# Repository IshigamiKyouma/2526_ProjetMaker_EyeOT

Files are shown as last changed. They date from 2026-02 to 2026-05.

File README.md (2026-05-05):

# 2526_ProjetMaker_EyeOT

Projet de MANSARD Johann réalisé dans le cadre de l'option Maker.\
Lien de la vidéo: https://youtube.com/shorts/I4skJVQ_Xr0?feature=share
Lien du répo avec les exos: https://github.com/IshigamiKyouma/2526_Maker_Exercises

## 1. Description du Projet et rétroplanning
### 1.1. Contexte et objectifs

En tant que joueur passionné de League of Legends et "Main Vel'Koz", j'ai toujours été fasciné par le concept de ce champion :
une entité du Néant qui déconstruit la réalité pour accumuler des connaissances.

<details>
  <summary>Cliquez ici pour voir le modèle 3D de Vel'Koz</summary>
  <br>
  <div align="center">
    Modèle 3D Vel'Koz
    <p><i>Rendu 3D du modèle Vel'Koz (Source : Riot Games)</i></p>
  </div>
</details>

L'idée de ce projet est née d'une envie simple: briser le quatrième mur. Je ne voulais plus que Vel'Koz soit uniquement une image sur mon écran, mais qu'il devienne un compagnon physique capable de réagir, en temps réel, à l'intensité de mes parties.

L'objectif est de créer une figurine interactive qui agit comme une extension sensorielle du jeu. Grâce à l'intégration de l'API de Riot Games et de composants électroniques, la figurine "vit" au rythme de la faille:

* Réaction aux événements: Un feedback visuel lors de l'application des stacks de passif (LEDs hautes qui s'allument une à une) puis la centrale lors de l'activation du passif "Organic Deconstruction".

* Analyse des mouvements: Les tentacules se déplacent en fonction de la vitesse de déplacement en jeu

### 1.2. Solutions techniques

* **Cœur du système :** Microcontrôleur **STM32**, choisi pour sa gestion fluide des interruptions et ses multiples canaux PWM nécessaires au pilotage synchrone des servomoteurs et du bus NeoPixel.
* **Communication de données :** Script en **Python** interrogeant la *Live Client Data API* de Riot Games à haute fréquence (HTTPS) et transmettant les états à la STM via une liaison **Série (USB)**.
* **Actionneurs & Visuels :**  3 Servomoteurs pour l'animation cinétique.
    * 3 LEDs adressables (NeoPixel) pour les stacks et 1 bloc circulaire pour l'œil central.
* **Gestion de l'énergie :** Conception d'un **PCB dédié** à la distribution de puissance, incluant un filtrage par condensateurs pour lisser les appels de courant des servos et une alimentation externe **5V 3A**.
* **Structure & Design :** Modélisation CAO et impression 3D. Le châssis est conçu pour masquer l'électronique dans le socle.

---

### 1.3. Obtention des valeurs

Pour obtenir:
* la vitesse de déplacement du joueur: on utilisera directement l'API
* les stacks de passif: Apparaissent visuelement quand on clique sur un ennemie

### Mécanisme de mouvement : Le système à câbles
Pour reproduire le mouvement fluide et "invertébré" des tentacules de Vel'Koz avec seulement 3 servomoteurs, le projet utilise un système de **flexion par câbles (tendeurs)** :

* **Principe :** Chaque tentacule est imprimée en matériau semi-rigide ou composée de vertèbres articulées.
* **Transmission :** Un câble (type fil de pêche ou nylon) parcourt l'intérieur de la tentacule jusqu'à l'extrémité. 
* **Actionnement :** Le servomoteur, situé dans la base, tire sur le câble pour courber la structure. Un ressort interne ou la mémoire de forme du plastique permet le retour à la position initiale.
* **Résultat :** Cela permet d'obtenir une ondulation organique plutôt qu'une rotation robotique rigide.

---

### Rétro-planning

| Session | Phase | Objectif principal |
| --- | ----- | --- |
| **TP 1** | **PoC Logiciel** | Script Python : récupération des données API et envoi vers l'ESP32. |
| **TP 2** | **Électronique** | Montage breadboard : test simultané des 3 servos et des LEDs. |
| **TP 3** | **Design PCB** | Routage du circuit d'alimentation et préparation à la soudure. |
| **TP 4** | **Modélisation 3D** | CAO du corps et du mécanisme de tension des tentacules. |
| **TP 5** | **Mécanique** | Assemblage des servos et tests des câbles de traction. |
| **TP 6** | **Intégration** | Soudure finale sur PCB et insertion dans la structure 3D. |
| **TP 7** | **Calibration** | Mapping des data LoL -> angles de servos et finitions visuelles. |

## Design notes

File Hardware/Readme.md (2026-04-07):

On rentrera ici plus en détail dans les problèmes et solutions techniques trouvées.

### Mouvement des tentacules 

La solution usuelle pour simuler des tentacules utilise 4 servos par tentacule. Afin de rendre le système plus compact et simple à commander, on utilisera 1 seul moteur.

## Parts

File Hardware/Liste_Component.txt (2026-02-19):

3 Stepper motor : 11HS18-0674S / 14HM11-0404S 
3 motor driver: TM2225-SA-T
Neopixels : 
STM32: STM32G474RET6
Bloc secteur 5V 4A
3 level-shifter 3.3V -> 5V pour chaque moteur
1 level-shifter 3.3V -> 5V pour les neopixels
1 Step-Down Alim-> STM : Wurth	171013801

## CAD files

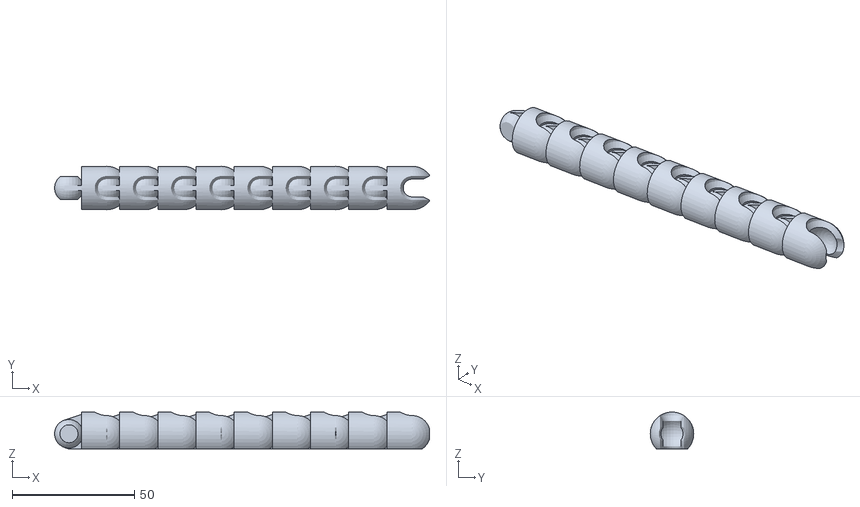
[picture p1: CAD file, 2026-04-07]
CAD/Articulated Vel Koz/articulated_velkoz_side_tentacle_x2.stl
153.2 x 17.8 x 15.1

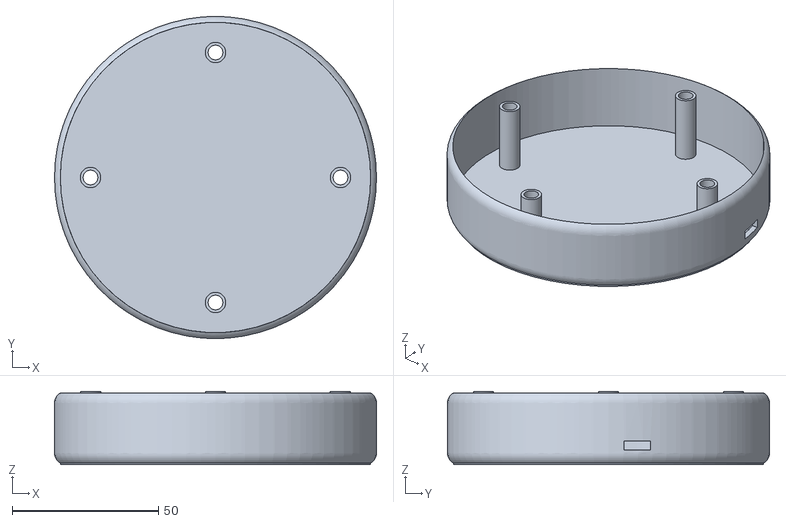
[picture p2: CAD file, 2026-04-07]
CAD/base_velkoz.stl
110.0 x 110.0 x 25.0

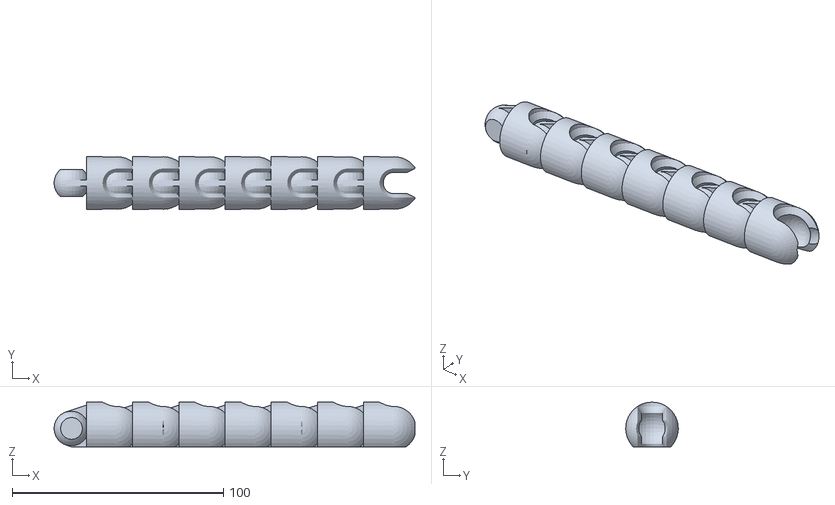
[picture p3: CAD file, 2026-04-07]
CAD/Articulated Vel Koz/articulated_velkoz_rear_tentacle.stl
170.8 x 24.9 x 21.1

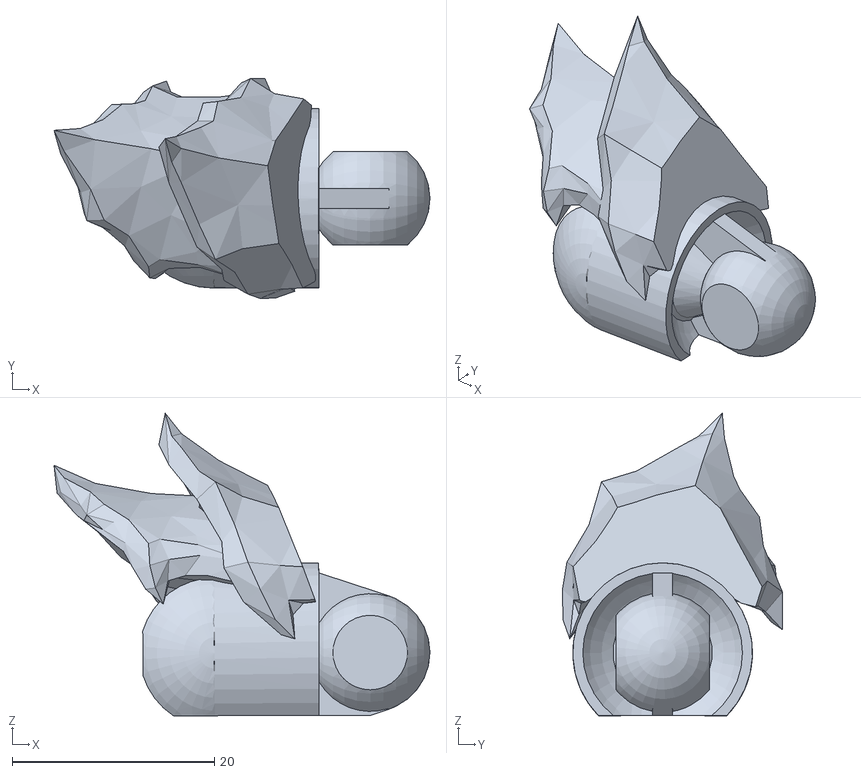
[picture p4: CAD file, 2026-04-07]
CAD/Articulated Vel Koz/articulated_velkoz_right_shoulder.stl
37.2 x 21.8 x 30.0

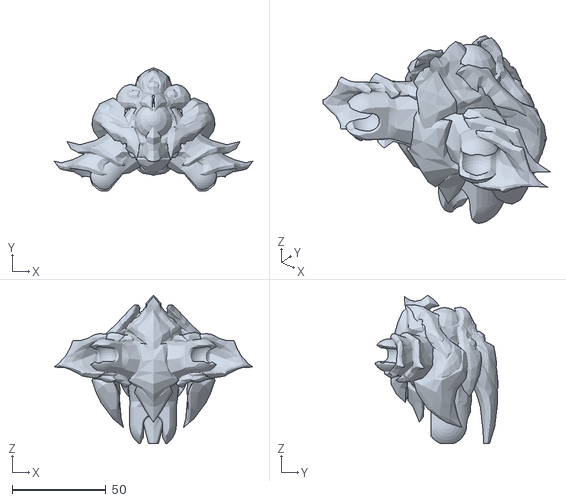
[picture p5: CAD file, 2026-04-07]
CAD/Articulated Vel Koz/articulated_velkoz_body.stl
106.0 x 65.8 x 79.0

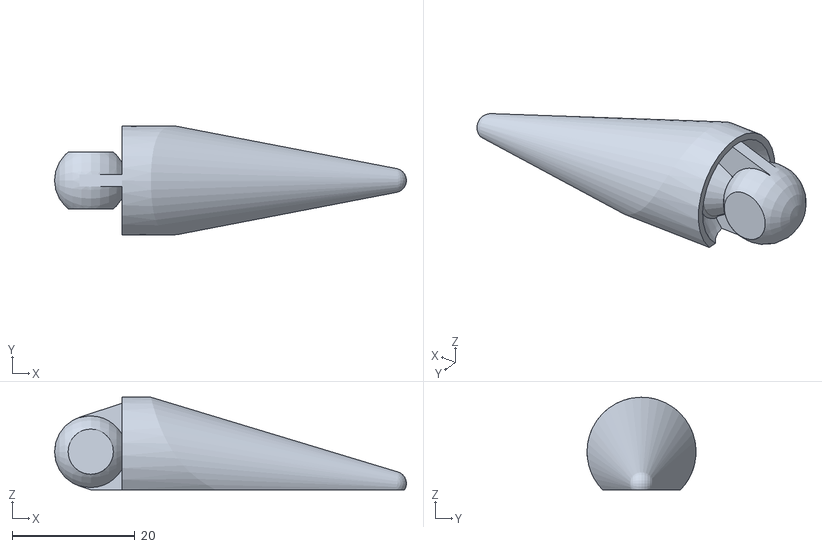
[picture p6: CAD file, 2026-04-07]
CAD/Articulated Vel Koz/articulated_velkoz_side_tip_x2.stl
57.4 x 17.8 x 15.1

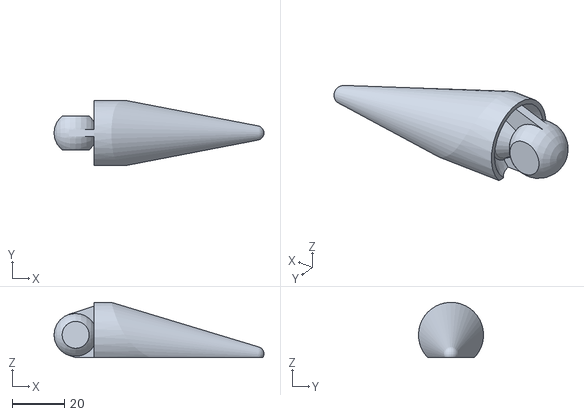
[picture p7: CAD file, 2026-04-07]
CAD/Articulated Vel Koz/articulated_velkoz_rear_tip.stl
80.4 x 24.9 x 21.1

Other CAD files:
CAD/velkoz_base.3mf
CAD/Articulated Vel Koz/articulated_velkoz_left_shoulder.stl
CAD/velkoz_base.stl

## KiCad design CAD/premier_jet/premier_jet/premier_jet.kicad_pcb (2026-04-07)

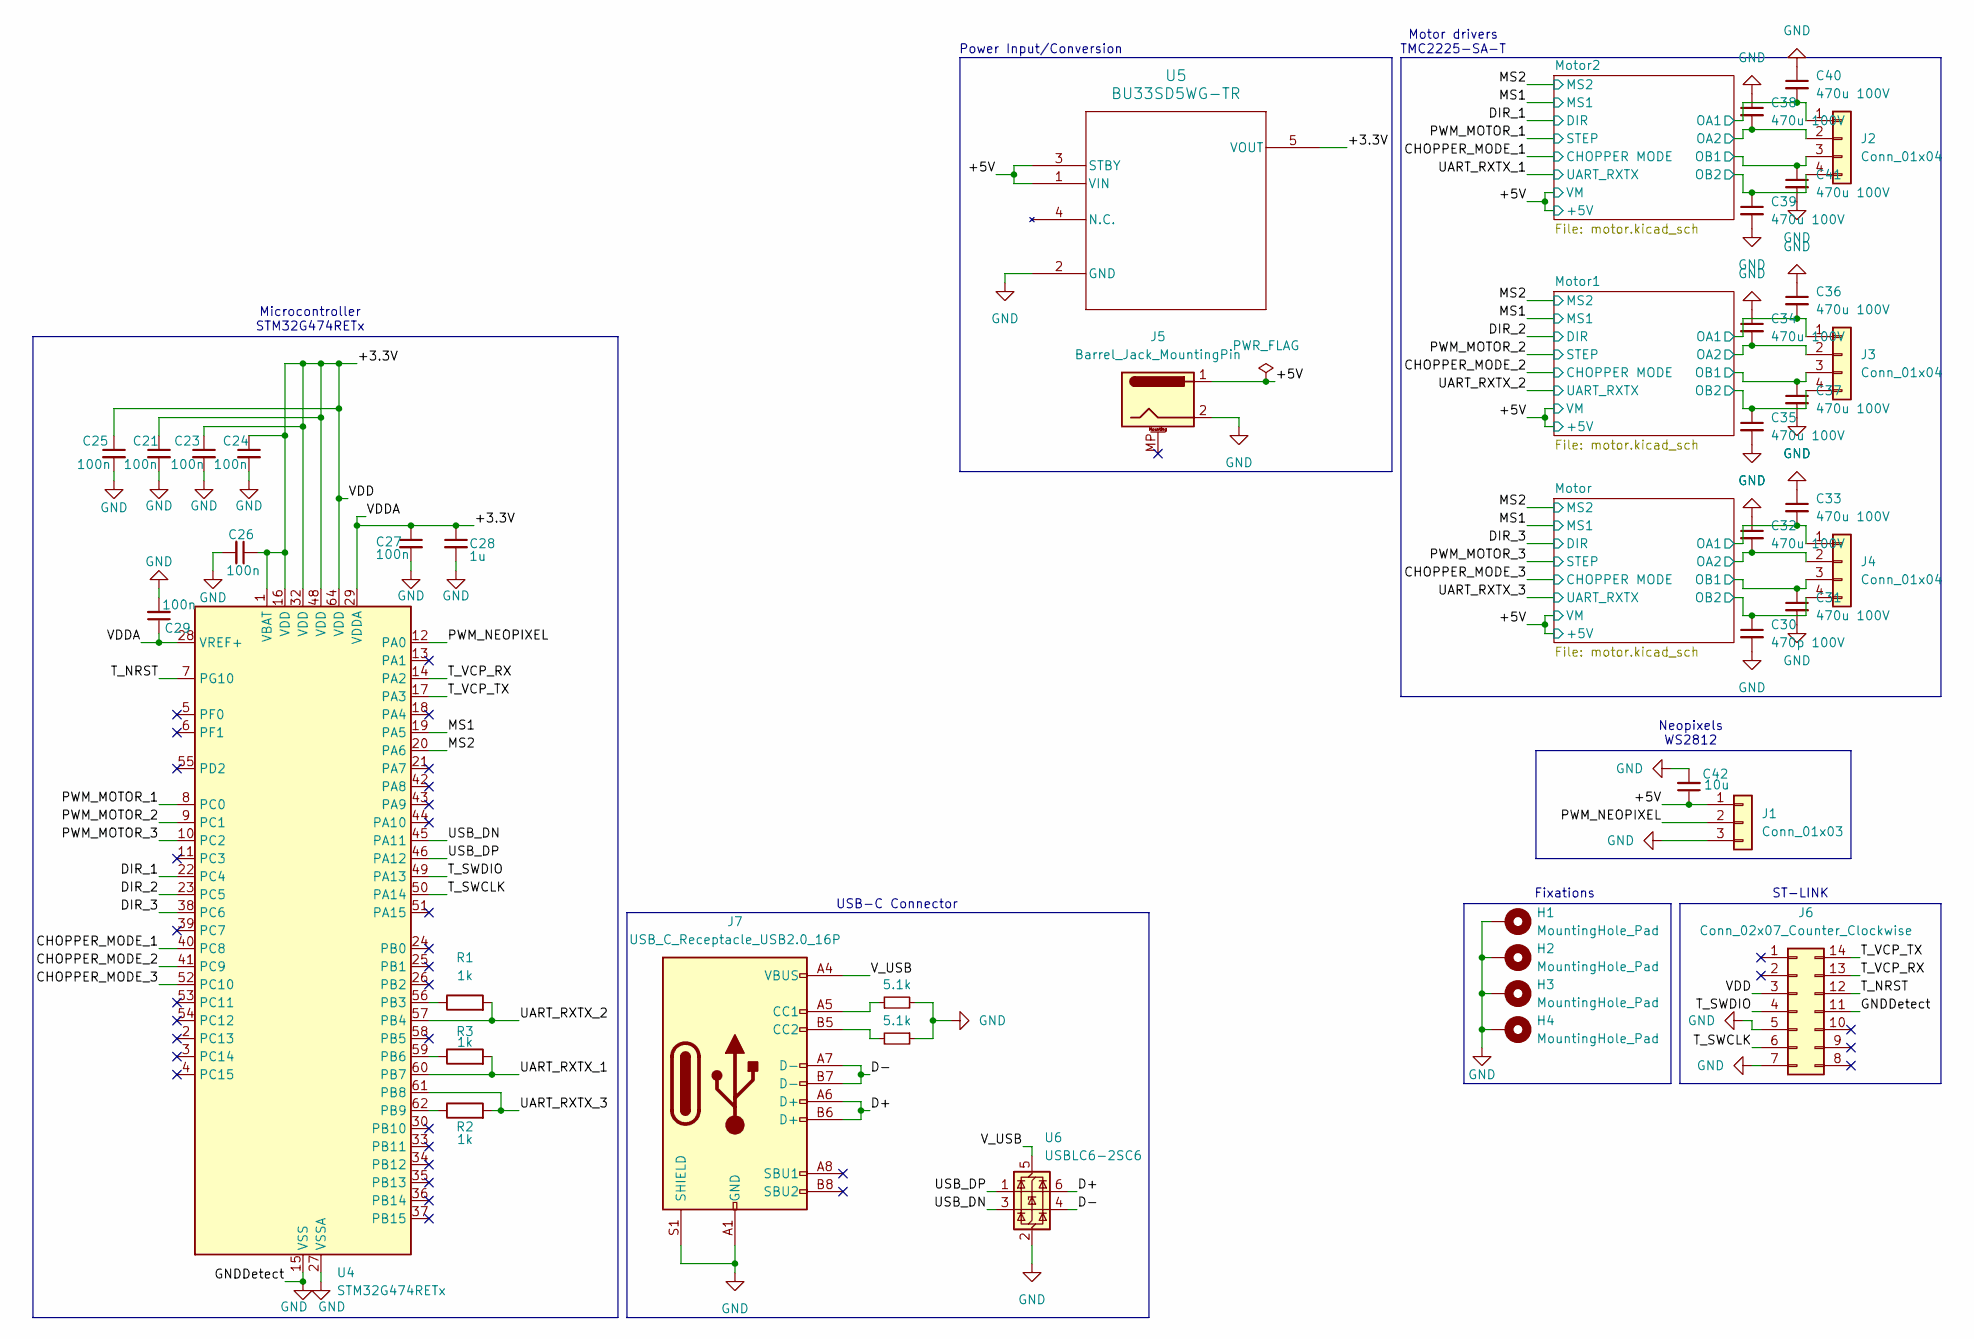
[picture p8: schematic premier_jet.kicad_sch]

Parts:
C21, C23, C24, C25, C26, C27, C29: 100n; C_0402_1005Metric
C28: 1u; C_0402_1005Metric
C30: 470p 100V; C_0603_1608Metric
C31, C32, C33, C34, C35, C36, C37, C38, C39, C40, C41: 470u 100V; C_0603_1608Metric
C42: 10u; C_0603_1608Metric
H1, H2, H3, H4: MountingHole_Pad; MountingHole_3.2mm_M3_Pad
J1: Conn_01x03; JST_PH_B3B-PH-K_1x03_P2.00mm_Vertical
J2, J3, J4: Conn_01x04; JST_PH_B4B-PH-K_1x04_P2.00mm_Vertical
J5: Barrel_Jack_MountingPin; BarrelJack_Wuerth_694106106102_2.0x5.5mm
J6: Conn_02x07_Counter_Clockwise; PinHeader_2x07_P2.54mm_Vertical_SMD
J7: USB_C_Receptacle_USB2.0_16P; USB_C_Receptacle_GCT_USB4105-xx-A_16P_TopMnt_Horizontal
R1, R2, R3: 1k; R_0402_1005Metric
R4, R5: 5.1k; R_0805_2012Metric
U4: STM32G474RETx; LQFP-64_10x10mm_P0.5mm
U5: BU33SD5WG-TR; SSOP5_ROM
U6: USBLC6-2SC6; SOT-23-6

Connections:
/+3.3V: C21.1, C23.1, C24.1, C25.1, C26.1, C27.1, C28.1, C29.1, J6.3, U4.1 (VBAT), U4.16 (VDD), U4.28 (VREF+), U4.29 (VDDA), U4.32 (VDD), U4.48 (VDD), U4.64 (VDD), U5.5 (VOUT)
/+5V: C42.1, J1.1, J5.1, U5.1 (VIN), U5.3 (STBY); also elsewhere on the board
/CHOPPER_MODE_1: U4.40 (PC8); also elsewhere on the board
/CHOPPER_MODE_2: U4.41 (PC9); also elsewhere on the board
/CHOPPER_MODE_3: U4.52 (PC10); also elsewhere on the board
/D+: J7.A6 (D+), J7.B6 (D+), U6.6 (I/O1)
/D-: J7.A7 (D-), J7.B7 (D-), U6.4 (I/O2)
/DIR_1: U4.22 (PC4); also elsewhere on the board
/DIR_2: U4.23 (PC5); also elsewhere on the board
/DIR_3: U4.38 (PC6); also elsewhere on the board
/MS1: U4.19 (PA5); also elsewhere on the board
/MS2: U4.20 (PA6); also elsewhere on the board
/Motor1/OA1: C36.2, J3.1; also elsewhere on the board
/Motor1/OA2: C34.2, J3.2; also elsewhere on the board
/Motor1/OB1: C37.1, J3.3; also elsewhere on the board
/Motor1/OB2: C35.1, J3.4; also elsewhere on the board
/Motor2/OA1: C40.2, J2.1; also elsewhere on the board
/Motor2/OA2: C38.2, J2.2; also elsewhere on the board
/Motor2/OB1: C41.1, J2.3; also elsewhere on the board
/Motor2/OB2: C39.1, J2.4; also elsewhere on the board
/Motor/OA1: C33.2, J4.1; also elsewhere on the board
/Motor/OA2: C32.2, J4.2; also elsewhere on the board
/Motor/OB1: C31.1, J4.3; also elsewhere on the board
/Motor/OB2: C30.1, J4.4; also elsewhere on the board
/PWM_MOTOR_1: U4.8 (PC0); also elsewhere on the board
/PWM_MOTOR_2: U4.9 (PC1); also elsewhere on the board
/PWM_MOTOR_3: U4.10 (PC2); also elsewhere on the board
/PWM_NEOPIXEL: J1.2, U4.12 (PA0)
/T_NRST: J6.12, U4.7 (PG10)
/T_SWCLK: J6.6, U4.50 (PA14)
/T_SWDIO: J6.4, U4.49 (PA13)
/T_VCP_RX: J6.13, U4.14 (PA2)
/T_VCP_TX: J6.14, U4.17 (PA3)
/UART_RXTX_1: R3.2, U4.60 (PB7); also elsewhere on the board
/UART_RXTX_2: R1.2, U4.57 (PB4); also elsewhere on the board
/UART_RXTX_3: R2.2, U4.61 (PB8); also elsewhere on the board
/USB_DN: U4.45 (PA11), U6.3 (I/O2)
/USB_DP: U4.46 (PA12), U6.1 (I/O1)
/V_USB: J7.A4 (VBUS), J7.A9 (VBUS), J7.B4 (VBUS), J7.B9 (VBUS), U6.5 (VBUS)
GND: C21.2, C23.2, C24.2, C25.2, C26.2, C27.2, C28.2, C29.2, C30.2, C31.2, C32.1, C33.1, C34.1, C35.2, C36.1, C37.2, C38.1, C39.2, C40.1, C41.2, C42.2, H1.1, H2.1, H3.1, H4.1, J1.3, J5.2, J6.5, J6.7, J6.11, J7.A1 (GND), J7.A12 (GND), J7.B1 (GND), J7.B12 (GND), J7.S1 (SHIELD), R4.2, R5.1, U4.15 (VSS), U4.27 (VSSA), U4.31 (VSS), U4.47 (VSS), U4.63 (VSS), U5.2 (GND), U6.2 (GND); also elsewhere on the board
unnamed: J7.A5 (CC1), R4.1
unnamed: J7.B5 (CC2), R5.2
unnamed: R1.1, U4.56 (PB3)
unnamed: R3.1, U4.59 (PB6)
unnamed: R2.1, U4.62 (PB9)

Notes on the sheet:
Motor drivers TMC2225-SA-T
Microcontroller STM32G474RETx
Neopixels WS2812
Power Input/Conversion
USB-C Connector
Fixations
ST-LINK

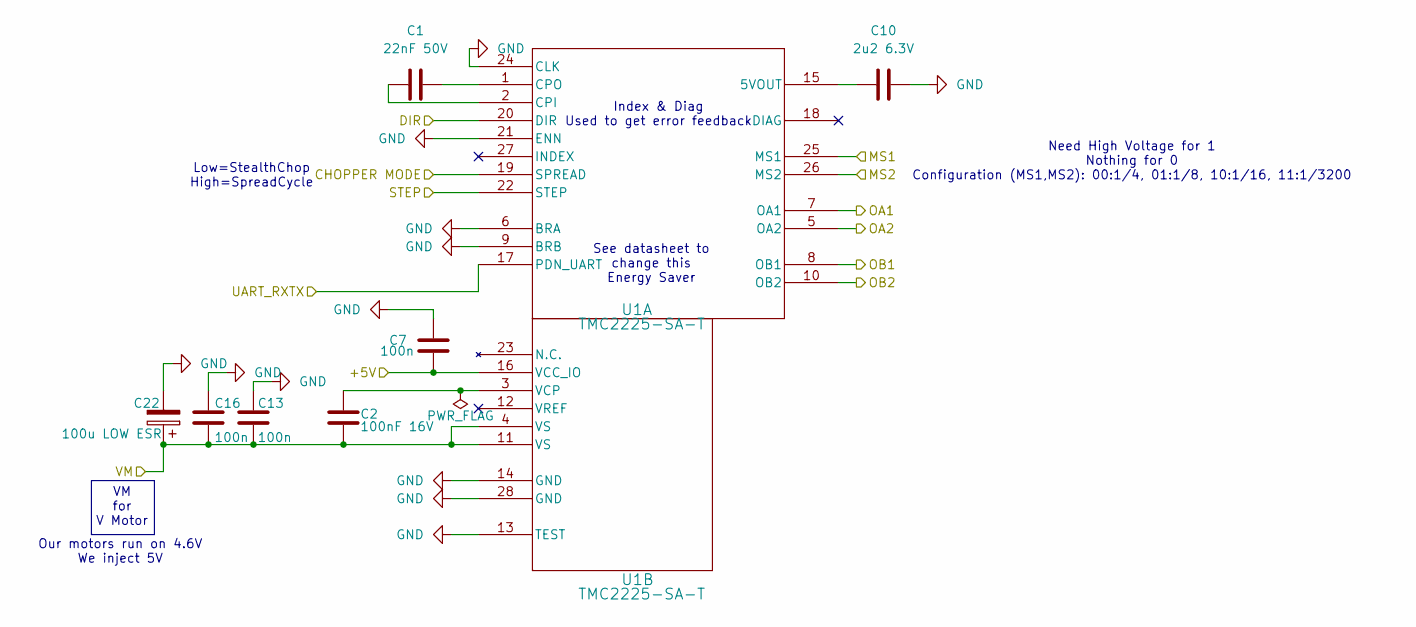
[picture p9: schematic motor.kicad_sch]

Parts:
C1: 22nF 50V; C_0603_1608Metric
C2: 100nF 16V; C_0402_1005Metric
C7, C13, C16: 100n; C_0402_1005Metric
C10: 2u2 6.3V; C_0402_1005Metric
C22: 100u LOW ESR; CP_Elec_6.3x5.4
U1: TMC2225-SA-T; HTSSOP28_TMC2225_TRI

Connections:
/+5V: C2.2, C7.2, C13.2, C16.2, C22.1, U1.4 (VS), U1.11 (VS), U1.16 (VCC_IO); also elsewhere on the board
/CHOPPER_MODE_3: U1.19 (SPREAD); also elsewhere on the board
/DIR_3: U1.20 (DIR); also elsewhere on the board
/MS1: U1.25 (MS1); also elsewhere on the board
/MS2: U1.26 (MS2); also elsewhere on the board
/Motor/OA1: U1.7 (OA1); also elsewhere on the board
/Motor/OA2: U1.5 (OA2); also elsewhere on the board
/Motor/OB1: U1.8 (OB1); also elsewhere on the board
/Motor/OB2: U1.10 (OB2); also elsewhere on the board
/PWM_MOTOR_3: U1.22 (STEP); also elsewhere on the board
/UART_RXTX_3: U1.17 (PDN_UART); also elsewhere on the board
GND: C7.1, C10.2, C13.1, C16.1, C22.2, U1.6 (BRA), U1.9 (BRB), U1.13 (TEST), U1.14 (GND), U1.21 (ENN), U1.24 (CLK), U1.28 (GND); also elsewhere on the board
unnamed: C10.1, U1.15 (5VOUT)
unnamed: C1.1, U1.2 (CPI)
unnamed: C1.2, U1.1 (CPO)
unnamed: C2.1, U1.3 (VCP)

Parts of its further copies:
C3, C12: 100u LOW ESR; CP_Elec_6.3x5.4
C4, C5, C9, C14, C15, C19: 100n; C_0402_1005Metric
C6, C17: 100nF 16V; C_0402_1005Metric
C8, C18: 22nF 50V; C_0603_1608Metric
C11, C20: 2u2 6.3V; C_0402_1005Metric
U2, U3: TMC2225-SA-T; HTSSOP28_TMC2225_TRI

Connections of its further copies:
/+5V: C3.1, C4.2, C5.2, C6.2, C9.2, C12.1, C14.2, C15.2, C17.2, C19.2, U2.4 (VS), U2.11 (VS), U2.16 (VCC_IO), U3.4 (VS), U3.11 (VS), U3.16 (VCC_IO); also elsewhere on the board
/CHOPPER_MODE_1: U3.19 (SPREAD); also elsewhere on the board
/CHOPPER_MODE_2: U2.19 (SPREAD); also elsewhere on the board
/DIR_1: U3.20 (DIR); also elsewhere on the board
/DIR_2: U2.20 (DIR); also elsewhere on the board
/MS1: U2.25 (MS1), U3.25 (MS1); also elsewhere on the board
/MS2: U2.26 (MS2), U3.26 (MS2); also elsewhere on the board
/Motor1/OA1: U2.7 (OA1); also elsewhere on the board
/Motor1/OA2: U2.5 (OA2); also elsewhere on the board
/Motor1/OB1: U2.8 (OB1); also elsewhere on the board
/Motor1/OB2: U2.10 (OB2); also elsewhere on the board
/Motor2/OA1: U3.7 (OA1); also elsewhere on the board
/Motor2/OA2: U3.5 (OA2); also elsewhere on the board
/Motor2/OB1: U3.8 (OB1); also elsewhere on the board
/Motor2/OB2: U3.10 (OB2); also elsewhere on the board
/PWM_MOTOR_1: U3.22 (STEP); also elsewhere on the board
/PWM_MOTOR_2: U2.22 (STEP); also elsewhere on the board
/UART_RXTX_1: U3.17 (PDN_UART); also elsewhere on the board
/UART_RXTX_2: U2.17 (PDN_UART); also elsewhere on the board
GND: C3.2, C4.1, C5.1, C9.1, C11.2, C12.2, C14.1, C15.1, C19.1, C20.2, U2.6 (BRA), U2.9 (BRB), U2.13 (TEST), U2.14 (GND), U2.21 (ENN), U2.24 (CLK), U2.28 (GND), U3.6 (BRA), U3.9 (BRB), U3.13 (TEST), U3.14 (GND), U3.21 (ENN), U3.24 (CLK), U3.28 (GND); also elsewhere on the board
unnamed: C11.1, U2.15 (5VOUT)
unnamed: C8.1, U2.2 (CPI)
unnamed: C8.2, U2.1 (CPO)
unnamed: C6.1, U2.3 (VCP)
unnamed: C20.1, U3.15 (5VOUT)
unnamed: C18.1, U3.2 (CPI)
unnamed: C18.2, U3.1 (CPO)
unnamed: C17.1, U3.3 (VCP)

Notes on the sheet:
VM for V Motor
Low=StealthChop High=SpreadCycle
See datasheet to change this Energy Saver
Our motors run on 4.6V We inject 5V
Index & Diag Used to get error feedback
Need High Voltage for 1 Nothing for 0 Configuration (MS1,MS2): 00:1/4, 01:1/8, 10:1/16, 11:1/3200

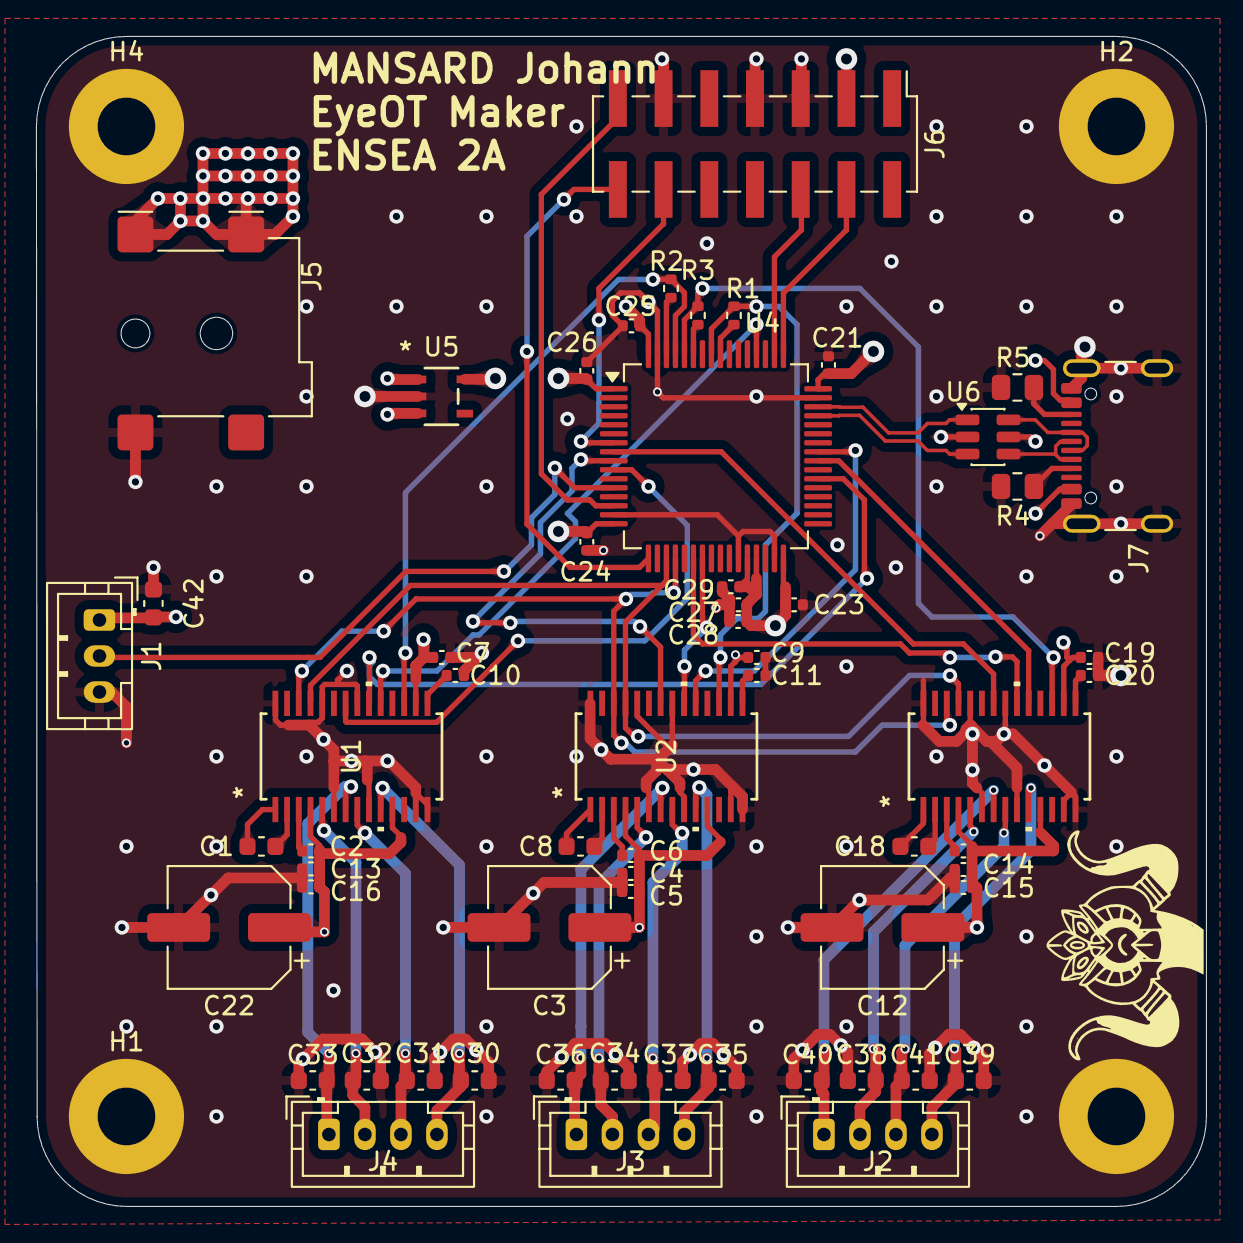
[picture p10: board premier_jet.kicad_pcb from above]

Board: 4 copper layers, 65.0 x 65.0 mm, 64 parts (0 on the bottom side), 57 nets.

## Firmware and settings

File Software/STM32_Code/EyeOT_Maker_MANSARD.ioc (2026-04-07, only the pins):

Mcu.UserName=STM32G474RETx
PA0.Signal=S_TIM2_CH1
PA11.Signal=USB_DM
PA12.Signal=USB_DP
PA13.Signal=SYS_JTMS-SWDIO
PA14.Signal=SYS_JTCK-SWCLK
PA5.Signal=GPIO_Output
PA6.Signal=GPIO_Output
PB3.Signal=USART2_TX
PB4.Signal=USART2_RX
PB6.Signal=USART1_TX
PB7.Signal=USART1_RX
PB8-BOOT0.Signal=USART3_RX
PB9.Signal=USART3_TX
PC0.Signal=S_TIM1_CH1
PC1.Signal=S_TIM1_CH2
PC10.Signal=GPIO_Output
PC2.Signal=S_TIM1_CH3
PC4.Signal=GPIO_Output
PC5.Signal=GPIO_Output
PC6.Signal=GPIO_Output
PC8.Signal=GPIO_Output
PC9.Signal=GPIO_Output

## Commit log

2026-02-18 :CAD added
2026-02-18 :Hardware added
    [motor.kicad_sch, premier_jet.kicad_pcb, premier_jet.kicad_sch]
2026-02-18 removed ussb-uart bridge
2026-02-19 Updated KiCad
    [motor.kicad_sch, premier_jet.kicad_pcb, premier_jet.kicad_sch]
2026-03-08 Update pcb
    [motor.kicad_sch, premier_jet.kicad_pcb, premier_jet.kicad_sch]
2026-04-07 Long overdue update
    [articulated_velkoz_body.stl, articulated_velkoz_left_shoulder.stl, articulated_velkoz_rear_tentacle.stl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]
